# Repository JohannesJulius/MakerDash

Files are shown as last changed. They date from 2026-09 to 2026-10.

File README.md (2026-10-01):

# MakerDash

> Früher „Pico Dashboard“.

Ein selbstgebautes Mischpult für den PC: drei Fader, ein Drehgeber und ein OLED-Display an einem
Raspberry Pi Pico 2 steuern Systemlautstärke, Mikrofon und einzelne Programme unter Windows.

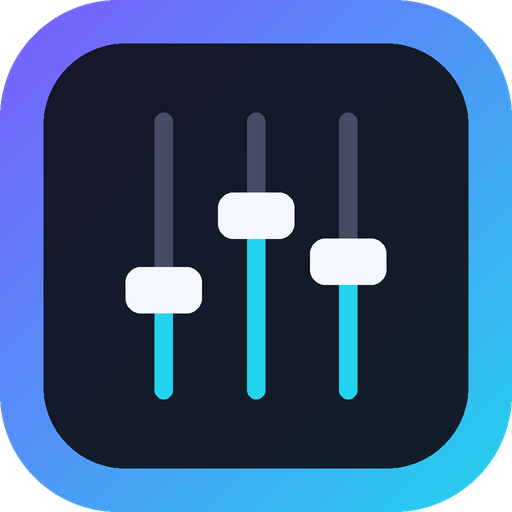
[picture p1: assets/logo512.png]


## Funktionen

- **Fader 1/2:** standardmäßig Systemlautstärke und Mikrofon (in der App frei belegbar)
- **Fader 3:** ein Programm oder eine Gruppe nach Wahl – am Dashboard im Menü oder in der App auswählbar
- **Gruppen** wie in Wave Link: mehrere Programme (z. B. alle Spiele) auf einem Fader
- **Alle Fader frei belegbar:** System, Mikrofon, Programm, Gruppe oder das aktive Fenster
- **Stummschalten** per langem Druck auf den Drehgeber, mit Anzeige auf dem Display
- **Menü am Dashboard:** Programm für Fader 3, Ausgabegerät und Mikrofon umschalten
- **Display:** Start-Animation, Lautstärke-Anzeige, Bildschirmschoner
- **App:** moderne Oberfläche, Live-Anzeige, Umbenennen/Ausblenden von Programmen und Geräten
- **Firmware-Verwaltung:** Die App spielt die Pico-Software selbst auf und aktualisiert sie
- **Automatische Updates** über GitHub Releases

## Installation

1. Neueste `MakerDash-Setup.exe` unter **Releases** herunterladen und starten.
2. Der Einrichtungsassistent führt durch das Anschließen. Ein neuer Pico wird im BOOTSEL-Modus
   (Taste gedrückt halten und einstecken) erkannt und komplett eingerichtet.

Benötigt Windows 10/11 (64 Bit) mit WebView2 Runtime (bei Windows 11 vorinstalliert).

## Verdrahtung (Standard)

| Bauteil | Pin |
|---|---|
| Fader 1 | GP28 |
| Fader 2 | GP27 |
| Fader 3 | GP26 |
| Encoder A / B / Taster | GP10 / GP11 / GP12 |
| OLED SDA / SCL | GP4 / GP5 |
| Fader & OLED Versorgung | 3V3(OUT), GND |

Die Belegung lässt sich in der App unter **Dashboard → Verdrahtung** ändern.

## Neue Version veröffentlichen

1. Versionsnummer in der Datei `VERSION` erhöhen (z. B. `2.1.0`)
2. optional: Beschreibung in `release-notes/v2.1.0.md` anlegen
3. committen und auf `main` pushen

GitHub baut daraufhin App und Installer (`.github/workflows/release.yml`), legt den Tag `v2.1.0` an
und veröffentlicht alles als Release. (Ein gepushter Tag `v*` funktioniert ebenfalls.)
Installierte Apps finden das Update automatisch. Wird `firmware/code.py` (`FW_VERSION`) geändert,
aktualisiert die App danach auch das Dashboard.

> Das Repository muss **öffentlich** sein, damit die App Updates ohne Anmeldung abrufen kann.

## Aufbau

| Pfad | Inhalt |
|---|---|
| `*.go` | Windows-App (Go, ohne cgo) |
| `ui/index.html` | Oberfläche (läuft in WebView2) |
| `firmware/` | Pico-Firmware (CircuitPython), wird in die App eingebettet |
| `installer/` | NSIS-Installer |

Lokal bauen (Linux oder Windows, Go ≥ 1.24):

```bash
GOOS=windows GOARCH=amd64 go build -ldflags "-H windowsgui -X main.AppVersion=2.1.0" -o dist/MakerDash.exe .
cd installer && makensis -DVERSION=2.1.0 setup.nsi
```

Die Bibliotheken in `firmware/lib` stammen von Adafruit (MIT-Lizenz).

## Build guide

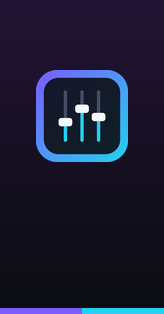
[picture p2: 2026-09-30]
installer/sidebar.bmp

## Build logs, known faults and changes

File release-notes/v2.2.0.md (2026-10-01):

## MakerDash 2.2.0

- **Gruppen** (wie die Kanäle in Wave Link): mehrere Programme zu einer Gruppe zusammenfassen –
  z. B. alle Spiele oder Musik und Browser – und mit einem Fader gemeinsam regeln. Gruppen anlegen
  unter **Programme**; am Dashboard stehen sie im Menü „Fader 3“ ganz oben
- **Alle Fader frei belegbar:** Fader 1 und 2 können jetzt auch ein Programm, eine Gruppe oder das
  aktive Fenster steuern
- **Aktives Fenster:** ein Fader regelt immer das Programm, das gerade im Vordergrund ist
- **Stummschalten per langem Druck** auf den Drehgeber (Standard: Mikrofon, einstellbar unter
  **Dashboard → Anzeige**). Das Display blendet „stumm“/„an“ ein und zeigt oben rechts dauerhaft an,
  wenn stummgeschaltet ist – auch wenn in Windows stummgeschaltet wurde
- Startet ein Programm, das ein Fader regelt, bekommt es sofort die Lautstärke des Faders
- Firmware 2.2.0 (wird von der App automatisch aufgespielt). Ein kurzer Druck auf den Drehgeber
  wirkt jetzt beim Loslassen

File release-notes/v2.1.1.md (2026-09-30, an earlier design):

## MakerDash 2.1.1

- **Behoben:** Schrift im Menü und auf dem Startbild des Dashboards war nach unten verrutscht
- Firmware 2.1.1 (wird von der App automatisch aufgespielt)

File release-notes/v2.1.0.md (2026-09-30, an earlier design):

## MakerDash 2.1.0

**Pico Dashboard heißt jetzt MakerDash.** Einstellungen und Autostart werden automatisch übernommen,
die alte Installation wird beim Update entfernt.

- **Neuer Bildschirmschoner:** Statt das Display abzuschalten, wandert ein gedimmtes MakerDash-Logo
  mit wippenden Mini-Fadern über den Bildschirm
- **Schnelleres Menü am Dashboard:** Schriften werden beim Start vorgeladen, Texte als ein Bild
  gezeichnet und das Display mit 400 kHz angesprochen
- **Neue Geräte-Grafik** in der App nach der Frontplatten-Zeichnung (Display oben, drei Fader,
  Drehgeber unten)
- Firmware 2.1.0 (wird von der App automatisch aufgespielt)

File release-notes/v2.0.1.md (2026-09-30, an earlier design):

## Pico Dashboard 2.0.1

- **Behoben:** Das Fenster blieb schwarz/leer – die Oberfläche wird jetzt zuverlässig angezeigt
- Updates lassen sich jetzt auch direkt über das Tray-Menü installieren (Rechtsklick auf das Symbol)
- Ausführlichere Einträge im Log zur Fehlersuche

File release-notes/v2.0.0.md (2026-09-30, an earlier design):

## Pico Dashboard 2.0

- **Neue Oberfläche** im dunklen Design mit Live-Anzeige der Fader
- **Firmware wird automatisch verwaltet:** Die App erkennt das Dashboard, spielt Updates selbst auf – kein Dateien-Kopieren mehr
- **Neuen Pico einrichten:** CircuitPython wird automatisch heruntergeladen und installiert (BOOTSEL-Modus)
- **Automatische Updates** der App über GitHub
- **Dashboard:** Start-Animation, Lautstärke-Anzeige beim Bewegen eines Faders, Bildschirmschoner
- Pin-Belegung und Anzeige-Einstellungen direkt in der App
- Fader 1 und Fader 3 standardmäßig getauscht (Fader 1 = GP28, Fader 3 = GP26)

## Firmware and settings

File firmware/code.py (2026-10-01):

# MakerDash – Firmware für Raspberry Pi Pico 2 (CircuitPython 9/10)
#
# Diese Datei wird von der App "MakerDash" installiert und aktualisiert.
# Einstellungen (Pins usw.) stehen in settings.toml und werden in der App geändert.

FW_VERSION = "2.2.0"
PROTO = 2
BOOT_MARKER = "DASHBOOT 2"

import os
import math
import time
import board
import busio
import displayio
import i2cdisplaybus
import terminalio
import rotaryio
import keypad
import usb_cdc
import supervisor
import microcontroller
import vectorio
from analogio import AnalogIn
import adafruit_displayio_ssd1306
from adafruit_display_text import bitmap_label
from adafruit_bitmap_font import bitmap_font


# ======================= Einstellungen (settings.toml) =======================

def cfg_str(name, standard):
    try:
        v = os.getenv(name)
    except Exception:
        v = None
    return standard if v is None else str(v)


def cfg_int(name, standard):
    try:
        return int(cfg_str(name, str(standard)))
    except ValueError:
        return standard


def cfg_pin(name, standard):
    return getattr(board, cfg_str(name, standard), getattr(board, standard))


PIN_FADER = (cfg_pin("DASH_FADER1", "GP28"),
             cfg_pin("DASH_FADER2", "GP27"),
             cfg_pin("DASH_FADER3", "GP26"))
FADER_INVERT = cfg_str("DASH_FADER_INVERT", "000")
PIN_ENC_A = cfg_pin("DASH_ENC_A", "GP10")
PIN_ENC_B = cfg_pin("DASH_ENC_B", "GP11")
PIN_ENC_SW = cfg_pin("DASH_ENC_SW", "GP12")
ENC_DIVISOR = cfg_int("DASH_ENC_DIVISOR", 4)
ENC_REVERSE = cfg_int("DASH_ENC_REVERSE", 0)
PIN_SDA = cfg_pin("DASH_SDA", "GP4")
PIN_SCL = cfg_pin("DASH_SCL", "GP5")
I2C_FREQ = cfg_int("DASH_I2C_FREQ", 400000)      # SSD1306 schafft 400 kHz (Fast Mode)
ANIMATION = cfg_int("DASH_ANIMATION", 1)

# Laufzeit-Einstellungen (werden von der App per CFG aktualisiert)
helligkeit = cfg_int("DASH_BRIGHTNESS", 100) / 100
schoner_sek = cfg_int("DASH_SAVER", 300)          # 0 = aus
overlay_an = cfg_int("DASH_OVERLAY", 1)

UNTEN_SCHWELLE = 15         # Fader 3 gilt als "unten" bei Wert <= 15 (von 1000)
BLINK_SEKUNDEN = 0.4
MENU_TIMEOUT = 15
PC_TIMEOUT = 8
OVERLAY_SEK = 1.5
LANG_SEK = 0.7             # so lange gedrückt halten = Stummschalten
AKTIV_SCHWELLE = 15         # so viel muss sich ein Fader bewegen, um als Bedienung zu zählen

# ======================= Hardware =======================

ser = usb_cdc.data
if ser is not None:
    ser.timeout = 0
    ser.write_timeout = 0.05


def senden(zeile):
    if ser is None or not ser.connected:
        return
    try:
        ser.write((zeile + "\n").encode("utf-8"))
    except Exception:
        pass


def boot_ok():
    try:
        with open("/boot_out.txt") as f:
            return BOOT_MARKER in f.read()
    except OSError:
        return False


BOOT_OK = boot_ok()


def boot_pruefen():
    """Nach einem Update ist die neue boot.py erst nach einem Reset aktiv.
    Einmal selbst neu starten; ein Merker im NVM verhindert eine Endlosschleife."""
    try:
        nvm = microcontroller.nvm
    except AttributeError:
        return
    if BOOT_OK:
        if nvm[0] != 0:
            nvm[0] = 0
        return
    try:
        with open("/boot.py") as f:
            neue_boot = BOOT_MARKER in f.read()
    except OSError:
        neue_boot = False
    if neue_boot and nvm[0] != 0xB2:
        nvm[0] = 0xB2
        time.sleep(0.5)
        microcontroller.reset()


boot_pruefen()


class Fader:
    """Liest einen Fader geglättet aus und liefert Werte 0–1000."""

    def __init__(self, pin, invert):
        self.adc = AnalogIn(pin)
        self.invert = invert
        self.gefiltert = self._roh()
        self.wert = self._skaliert(self.gefiltert)
        self.aktiv_wert = self.wert

    def _roh(self):
        s = 0
        for _ in range(8):
            s += self.adc.value
        return s / 8

    def _skaliert(self, roh):
        x = (roh - 400) / (65535 - 800)
        x = max(0.0, min(1.0, x))
        if self.invert:
            x = 1.0 - x
        return int(x * 1000 + 0.5)

    def lesen(self):
        """Neuer Wert bei Änderung, sonst None."""
        self.gefiltert += (self._roh() - self.gefiltert) * 0.3
        neu = self._skaliert(self.gefiltert)
        if abs(neu - self.wert) >= 4 or (neu != self.wert and neu in (0, 1000)):
            self.wert = neu
            return neu
        return None

    def bewegt(self):
        """True, wenn der Fader deutlich bewegt wurde (für Anzeige/Schoner)."""
        if abs(self.wert - self.aktiv_wert) >= AKTIV_SCHWELLE or (
                self.wert != self.aktiv_wert and self.wert in (0, 1000)):
            self.aktiv_wert = self.wert
            return True
        return False


fader = [Fader(PIN_FADER[i], FADER_INVERT[i:i + 1] == "1") for i in range(3)]

if ENC_REVERSE:
    PIN_ENC_A, PIN_ENC_B = PIN_ENC_B, PIN_ENC_A
encoder = rotaryio.IncrementalEncoder(PIN_ENC_A, PIN_ENC_B, divisor=ENC_DIVISOR)
letzte_pos = encoder.position
taster = keypad.Keys((PIN_ENC_SW,), value_when_pressed=False, pull=True)

# ======================= Display =======================
displayio.release_displays()
i2c = busio.I2C(PIN_SCL, PIN_SDA, frequency=I2C_FREQ)
bus = i2cdisplaybus.I2CDisplayBus(i2c, device_address=0x3C)
display = adafruit_displayio_ssd1306.SSD1306(bus, width=128, height=64)

WEISS = 0xFFFFFF
SCHWARZ = 0x000000
FONT_MENU = bitmap_font.load_font("/fonts/menu.bdf")
FONT_GROSS = bitmap_font.load_font("/fonts/big.bdf")
# BDF-Schriften laden Zeichen sonst erst bei Bedarf – jedes neue Zeichen durchsucht dann die
# ganze Datei. Das machte das Menü träge; deshalb nach der Start-Animation alles vorladen.
ZEICHEN = "".join(chr(c) for c in range(32, 127)) + "äöüÄÖÜß°"

PAL_WEISS = displayio.Palette(1)
PAL_WEISS[0] = WEISS


def helligkeit_setzen(wert):
    try:
        display.brightness = max(0.02, min(1.0, wert))
    except Exception:
        pass


helligkeit_setzen(helligkeit)


def rechteck(w, h, x, y):
    return vectorio.Rectangle(pixel_shader=PAL_WEISS, width=w, height=h, x=x, y=y)


def icon(muster, x, y):
    bmp = displayio.Bitmap(len(muster[0]), len(muster), 2)
    for yy, zeile in enumerate(muster):
        for xx, c in enumerate(zeile):
            bmp[xx, yy] = 1 if c == "1" else 0
    pal = displayio.Palette(2)
    pal[0] = SCHWARZ
    pal[1] = WEISS
    pal.make_transparent(0)
    return displayio.TileGrid(bmp, pixel_shader=pal, x=x, y=y)


ICON_LAUTSPRECHER = ("000001000", "000011000", "011111010", "011111001",
                     "011111001", "011111010", "000011000", "000001000")


# bitmap_label zeichnet ein Bitmap pro Text statt einer Kachel pro Buchstabe – deutlich schneller.
# Bei BDF-Schriften hält es aber die Schrifthöhe für die Oberlänge und zentriert auf einen vom Text
# abhängigen Kasten: Texte rutschten 6–9 Pixel nach unten. Mit Anker oben (y = 0) liegt die Schrift
# dagegen immer gleich; diese Tabelle rechnet darauf um, sodass alles wie mit label.Label sitzt.
# Werte je Schrift: (Höhe der Großbuchstaben, Abstand Ankerpunkt -> Oberkante Großbuchstaben)
KORREKTUR = {id(FONT_MENU): (9, 8), id(FONT_GROSS): (13, 9)}
_anker_y = {}


def _y_korrigiert(font, ay, y):
    k = KORREKTUR.get(id(font))
    if k is None:
        return y
    return y - int(ay * k[0]) - k[1]


def text(font, t, anker, pos, farbe=WEISS):
    ax, ay = anker
    bdf = id(font) in KORREKTUR
    lbl = bitmap_label.Label(font, text=t, color=farbe, anchor_point=(ax, 0) if bdf else anker,
                             anchored_position=(pos[0], _y_korrigiert(font, ay, pos[1])))
    _anker_y[id(lbl)] = (ay, pos[1])
    return lbl


def platzieren(lbl, x, y):
    """Wie anchored_position = (x, y), aber mit der Korrektur für BDF-Schriften."""
    ay = _anker_y[id(lbl)][0]
    _anker_y[id(lbl)] = (ay, y)
    lbl.anchored_position = (x, _y_korrigiert(lbl.font, ay, y))


def schrift_setzen(lbl, font, t):
    """Schrift und Text ändern; die Höhe wird für die neue Schrift neu berechnet."""
    if lbl.font is not font:
        lbl.font = font
        ay, y = _anker_y[id(lbl)]
        lbl.anchored_position = (lbl.anchored_position[0], _y_korrigiert(font, ay, y))
    if lbl.text != t:
        lbl.text = t


# --- Startbild ---
start = displayio.Group()
lbl_titel = text(terminalio.FONT, "Fader 3", (0, 0), (0, 0))
lbl_pc = text(terminalio.FONT, "", (1, 0), (127, 0))
# Stumm-Anzeige oben rechts: schwarze Schrift auf weißem Feld
mute_bg = rechteck(1, 11, 0, 0)
mute_bg.hidden = True
lbl_mute = text(terminalio.FONT, "", (1, 0), (125, 0), farbe=SCHWARZ)
lbl_name = text(FONT_GROSS, "", (0, 0.5), (0, 27))
ico_ausgabe = icon(ICON_LAUTSPRECHER, 0, 51)
lbl_ausgabe = text(FONT_MENU, "", (0, 0.5), (12, 55))
lbl_hinweis = text(terminalio.FONT, "", (0.5, 0.5), (64, 55))
for teil in (lbl_titel, lbl_pc, mute_bg, lbl_mute, lbl_name, rechteck(128, 1, 0, 44),
             ico_ausgabe, lbl_ausgabe, lbl_hinweis):
    start.append(teil)

# --- Menü (4 Zeilen, markierte Zeile invertiert) ---
ZEILEN = 4
ZEILENHOEHE = 16
menue = displayio.Group()
balken = rechteck(128, ZEILENHOEHE, 0, 0)
menue.append(balken)
menue_labels = []
menue_pfeile = []
for i in range(ZEILEN):
    mitte = i * ZEILENHOEHE + ZEILENHOEHE // 2
    l = text(FONT_MENU, "", (0, 0.5), (3, mitte))
    p = text(FONT_MENU, "", (1, 0.5), (126, mitte))
    menue.append(l)
    menue.append(p)
    menue_labels.append(l)
    menue_pfeile.append(p)

# --- Lautstärke-Anzeige ---
overlay = displayio.Group()
ov_name = text(FONT_MENU, "", (0.5, 0.5), (64, 8))
ov_wert = text(FONT_GROSS, "", (0.5, 0.5), (64, 30))
ov_rahmen = displayio.Group()
for r in (rechteck(120, 1, 4, 48), rechteck(120, 1, 4, 57), rechteck(1, 10, 4, 48),
          rechteck(1, 10, 123, 48)):
    ov_rahmen.append(r)
ov_fuell = rechteck(1, 6, 6, 50)
for teil in (ov_name, ov_wert, ov_rahmen, ov_fuell):
    overlay.append(teil)

# --- Update-Bildschirm ---
update_bild = displayio.Group()
upd_titel = text(FONT_MENU, "Update", (0.5, 0.5), (64, 12))
upd_text = text(terminalio.FONT, "Wird installiert ...", (0.5, 0.5), (64, 30))
upd_fuell = rechteck(1, 6, 6, 50)
for teil in (upd_titel, upd_text, rechteck(120, 1, 4, 48), rechteck(120, 1, 4, 57),
             rechteck(1, 10, 4, 48), rechteck(1, 10, 123, 48), upd_fuell):
    update_bild.append(teil)


# --- Bildschirmschoner: MakerDash-Logo wandert langsam über das Display ---
schoner = displayio.Group()
sch_knoepfe = []
for i in range(3):
    schoner.append(rechteck(1, 15, 2 + i * 6, 1))
    k = rechteck(5, 3, i * 6, 7)
    schoner.append(k)
    sch_knoepfe.append(k)
schoner.append(text(FONT_MENU, "MakerDash", (0, 0.5), (19, 8)))
SCH_W, SCH_H = 19 + 73, 17
sch_x, sch_y = 10.0, 20.0
sch_dx, sch_dy = 9.0, 5.0             # Pixel pro Sekunde
sch_zeit = 0.0


def schoner_schritt(t):
    """Bewegt das Logo (ca. 20 Bilder/s) und lässt die Mini-Fader wippen."""
    global sch_x, sch_y, sch_dx, sch_dy, sch_zeit
    dt = t - sch_zeit
    if dt < 0.05:
        return
    sch_zeit = t
    dt = min(dt, 0.2)
    sch_x += sch_dx * dt
    sch_y += sch_dy * dt
    if sch_x < 0 or sch_x > 128 - SCH_W:
        sch_dx = -sch_dx
        sch_x = max(0.0, min(128.0 - SCH_W, sch_x))
    if sch_y < 0 or sch_y > 64 - SCH_H:
        sch_dy = -sch_dy
        sch_y = max(0.0, min(64.0 - SCH_H, sch_y))
    schoner.x = int(sch_x)
    schoner.y = int(sch_y)
    for i, k in enumerate(sch_knoepfe):
        k.y = int(7 + 6 * math.sin(t * 1.6 + i * 2.1))


def start_animation():
    """Kurzes Logo beim Einschalten: drei Fader schieben sich in Position."""
    g = displayio.Group()
    spuren_x = (12, 24, 36)
    knoepfe = []
    for x in spuren_x:
        g.append(rechteck(1, 48, x, 8))
        k = rechteck(9, 5, x - 4, 51)
        g.append(k)
        knoepfe.append(k)
    t_gross = text(FONT_GROSS, "Maker", (0, 0.5), (128, 20))
    t_klein = text(FONT_GROSS, "Dash", (0, 0.5), (128, 42))
    t_ver = text(terminalio.FONT, "v" + FW_VERSION, (1, 1), (127, 64))
    t_ver.hidden = True
    for t in (t_gross, t_klein, t_ver):
        g.append(t)
    display.root_group = g
    ziele = (0.25, 0.7, 0.45)
    t0 = time.monotonic()
    dauer = 1.6
    while True:
        t = time.monotonic() - t0
        if t > dauer:
            break
        for i, k in enumerate(knoepfe):
            p = max(0.0, min(1.0, (t - i * 0.12) / 0.7))
            p = 1 - (1 - p) ** 3                      # sanft abbremsen
            k.y = int(51 - p * ziele[i] * 43)
        p = max(0.0, min(1.0, (t - 0.35) / 0.6))
        p = 1 - (1 - p) ** 3
        x = int(128 - p * (128 - 50))
        platzieren(t_gross, x, 20)
        p2 = max(0.0, min(1.0, (t - 0.5) / 0.6))
        p2 = 1 - (1 - p2) ** 3
        platzieren(t_klein, int(128 - p2 * (128 - 50)), 42)
        t_ver.hidden = t < 1.0
        time.sleep(0.015)
    return time.monotonic()


def schriften_vorladen():
    for f in (FONT_MENU, FONT_GROSS):
        try:
            f.load_glyphs(ZEICHEN)
        except Exception:
            pass


if ANIMATION:
    ende = start_animation()
    schriften_vorladen()                       # läuft, während das Logo noch steht
    rest = 0.5 - (time.monotonic() - ende)
    if rest > 0:
        time.sleep(rest)
else:
    schriften_vorladen()

# ======================= Zustand =======================
apps = []
ausgaben = []
ausgabe_idx = -1
mikros = []
mikro_idx = -1
f3_name = "-"
namen = ["Fader 1", "Fader 2", "Fader 3"]
gesperrt = False
letzte_rx = -100.0
modus = "START"         # START, HAUPT, PROG, AUSGABE, MIKRO
cursor = 0
scroll = 0
jetzt = time.monotonic()
letzte_eingabe = jetzt
letzte_aktivitaet = jetzt
overlay_bis = 0.0
schlaeft = False
gedimmt = False
update_laeuft = False
rx_puffer = b""
mute_an = False
mute_name = ""
mute_bekannt = False        # erst nach der ersten Meldung vom PC Änderungen einblenden
taste_seit = None           # Zeitpunkt, seit dem der Taster gedrückt ist
taste_lang = False


def pc_da():
    return ser is not None and ser.connected and time.monotonic() - letzte_rx < PC_TIMEOUT


def eintraege(m=None):
    """Liste aus (Text, Pfeil, Wert)."""
    modus_ = m or modus
    if modus_ == "HAUPT":
        return [("Zurück", False, None), ("Fader 3", True, None),
                ("Ausgabe", True, None), ("Mikrofon", True, None)]
    liste = [("Zurück", False, None)]
    if not pc_da():
        return liste + [("(kein PC)", False, None)]
    if modus_ == "PROG":
        if not apps:
            liste.append(("(kein Ton aktiv)", False, None))
        for n in apps:
            liste.append((("* " if n == f3_name else "  ") + n, False, n))
    elif modus_ == "AUSGABE":
        for i, n in enumerate(ausgaben):
            liste.append((("* " if i == ausgabe_idx else "  ") + n, False, n))
    elif modus_ == "MIKRO":
        if not mikros:
            liste.append(("(kein Mikrofon)", False, None))
        for i, n in enumerate(mikros):
            liste.append((("* " if i == mikro_idx else "  ") + n, False, n))
    return liste


def menue_zeichnen():
    global scroll, cursor
    liste = eintraege()
    cursor = max(0, min(cursor, len(liste) - 1))
    if cursor < scroll:
        scroll = cursor
    elif cursor >= scroll + ZEILEN:
        scroll = cursor - ZEILEN + 1
    scroll = max(0, min(scroll, max(0, len(liste) - ZEILEN)))
    for zeile in range(ZEILEN):
        idx = scroll + zeile
        t, pfeil, _ = liste[idx] if idx < len(liste) else ("", False, None)
        farbe = SCHWARZ if idx == cursor else WEISS
        # nur Geändertes anfassen – jede Änderung kostet Rechenzeit und Übertragung
        lbl, pf = menue_labels[zeile], menue_pfeile[zeile]
        if lbl.text != t:
            lbl.text = t
        if lbl.color != farbe:
            lbl.color = farbe
        p = ">" if pfeil else ""
        if pf.text != p:
            pf.text = p
        if pf.color != farbe:
            pf.color = farbe
    y = (cursor - scroll) * ZEILENHOEHE
    if balken.y != y:
        balken.y = y


def gross_setzen(lbl, t):
    schrift_setzen(lbl, FONT_GROSS, t)
    if lbl.bounding_box[2] > 124:
        schrift_setzen(lbl, FONT_MENU, t)


def start_zeichnen():
    if lbl_name.text != f3_name:
        gross_setzen(lbl_name, f3_name)
    da = pc_da()
    lbl_pc.text = "" if da else "kein PC"
    m = ""
    if da and mute_an:
        m = mute_name + " aus"
        if len(m) > 13:
            m = "STUMM"
    if lbl_mute.text != m:
        lbl_mute.text = m
        if m:
            w = lbl_mute.bounding_box[2]
            mute_bg.x = 125 - w - 2
            mute_bg.width = w + 4
    mute_bg.hidden = not m
    aus = ausgaben[ausgabe_idx] if 0 <= ausgabe_idx < len(ausgaben) else "-"
    if lbl_ausgabe.text != aus:
        lbl_ausgabe.text = aus


def bild_zeigen():
    """Zeigt das zum Zustand passende Bild."""
    if schlaeft and not update_laeuft:
        display.root_group = schoner
    elif update_laeuft:
        display.root_group = update_bild
    elif time.monotonic() < overlay_bis:
        display.root_group = overlay
    elif modus == "START":
        start_zeichnen()
        display.root_group = start
    else:
        menue_zeichnen()
        display.root_group = menue


def gehe_zu(neuer_modus, neuer_cursor=0):
    global modus, cursor, scroll, overlay_bis
    modus = neuer_modus
    cursor = neuer_cursor
    scroll = 0
    overlay_bis = 0
    bild_zeigen()


def cursor_auf(ziel_modus, name, standard=1):
    for i, (_, _, wert) in enumerate(eintraege(ziel_modus)):
        if wert is not None and wert == name:
            return i
    return standard


def overlay_zeigen(i):
    global overlay_bis
    if not overlay_an or update_laeuft:
        return
    ov_name.text = namen[i]
    if i == 2 and gesperrt:
        schrift_setzen(ov_wert, FONT_MENU, "ganz runter!")
    else:
        schrift_setzen(ov_wert, FONT_GROSS, "%d %%" % ((fader[i].wert + 5) // 10))
    ov_fuell.width = max(1, fader[i].wert * 116 // 1000)
    ov_rahmen.hidden = False
    ov_fuell.hidden = False
    overlay_bis = time.monotonic() + OVERLAY_SEK
    if display.root_group is not overlay:
        display.root_group = overlay


def overlay_text(name, wert):
    """Einblendung ohne Balken, z. B. "Mikrofon / stumm"."""
    global overlay_bis
    if not overlay_an or update_laeuft:
        return
    ov_name.text = name
    schrift_setzen(ov_wert, FONT_GROSS, wert)
    ov_rahmen.hidden = True
    ov_fuell.hidden = True
    overlay_bis = time.monotonic() + OVERLAY_SEK
    if display.root_group is not overlay:
        display.root_group = overlay


def aufwachen():
    """Bildschirmschoner beenden. Gibt True zurück, wenn der Bildschirm aus war."""
    global schlaeft, gedimmt, letzte_aktivitaet
    letzte_aktivitaet = time.monotonic()
    war_aus = schlaeft
    if schlaeft:
        schlaeft = False
        bild_zeigen()
    if gedimmt:
        helligkeit_setzen(helligkeit)
        gedimmt = False
    return war_aus


def taster_gedrueckt():
    global f3_name, gesperrt, ausgabe_idx, mikro_idx
    if modus == "START":
        gehe_zu("HAUPT", 1)
        return
    if modus == "HAUPT":
        if cursor == 0:
            gehe_zu("START")
        elif cursor == 1:
            gehe_zu("PROG", cursor_auf("PROG", f3_name))
        elif cursor == 2:
            aktiv = ausgaben[ausgabe_idx] if 0 <= ausgabe_idx < len(ausgaben) else None
            gehe_zu("AUSGABE", cursor_auf("AUSGABE", aktiv))
        else:
            aktiv = mikros[mikro_idx] if 0 <= mikro_idx < len(mikros) else None
            gehe_zu("MIKRO", cursor_auf("MIKRO", aktiv))
        return
    _, _, wert = eintraege()[cursor]
    if cursor == 0:
        gehe_zu("HAUPT", {"PROG": 1, "AUSGABE": 2, "MIKRO": 3}[modus])
    elif wert is None:
        pass
    elif modus == "PROG":
        if wert != f3_name:
            f3_name = wert
            namen[2] = wert
            gesperrt = True
        senden("SETAPP\t" + wert)
        gehe_zu("START")
    elif modus == "AUSGABE":
        if wert in ausgaben:
            ausgabe_idx = ausgaben.index(wert)
        senden("SETOUT\t" + wert)
        gehe_zu("START")
    elif modus == "MIKRO":
        if wert in mikros:
            mikro_idx = mikros.index(wert)
        senden("SETIN\t" + wert)
        gehe_zu("START")


def fader_senden(i, wert):
    senden("F\t%d\t%d" % (i + 1, wert))


def cfg_anwenden(teile):
    global helligkeit, schoner_sek, overlay_an
    for k in range(0, len(teile) - 1, 2):
        schluessel, wert = teile[k], teile[k + 1]
        try:
            if schluessel == "brightness":
                helligkeit = int(wert) / 100
                if not gedimmt:
                    helligkeit_setzen(helligkeit)
            elif schluessel == "saver":
                schoner_sek = int(wert)
            elif schluessel == "overlay":
                overlay_an = int(wert)
        except ValueError:
            pass
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

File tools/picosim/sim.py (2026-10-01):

import os, sys, types, time as _rt
from PIL import Image, ImageFont, ImageDraw

# Mit "pip install adafruit-blinka-displayio" laufen displayio, Schriften und Labels mit den echten
# Adafruit-Bibliotheken aus firmware/lib – die Bilder entsprechen dann pixelgenau dem Display.
# Ohne Blinka (oder mit SIM_FAKE=1) gibt es eine vereinfachte Nachbildung (Textpositionen ungenau).
_FWDIR = os.path.join(os.path.dirname(os.path.abspath(__file__)), "..", "..", "firmware")
REAL = os.environ.get("SIM_FAKE") is None
if REAL:
    try:
        sys.path.insert(0, os.path.join(_FWDIR, "lib"))
        import displayio as _rdio, vectorio as _rvio, terminalio as _rterm
        from adafruit_bitmap_font import bitmap_font as _rbf
        import adafruit_display_text as _radt
        from adafruit_display_text import bitmap_label as _rbl, label as _rlab
    except ImportError:
        REAL = False

# ---------- virtuelle Zeit & Szenario ----------
CLOCK = [0.0]
SCENARIO = None
class Stop(Exception): pass

tm = types.ModuleType("time")
tm.monotonic = lambda: CLOCK[0]
def _sleep(s):
    CLOCK[0] += max(s, 0.005)
    SCENARIO.tick()
tm.sleep = _sleep
sys.modules["time"] = tm

# ---------- board / busio ----------
board = types.ModuleType("board")
for n in ["GP%d" % i for i in range(29)]: setattr(board, n, n)
sys.modules["board"] = board
busio = types.ModuleType("busio"); busio.I2C = lambda scl, sda, frequency=100000: ("i2c", scl, sda, frequency); sys.modules["busio"] = busio

# ---------- analog ----------
ADC = {}
analogio = types.ModuleType("analogio")
class AnalogIn:
    def __init__(self, pin): self.pin = pin; ADC.setdefault(pin, 30000)
    @property
    def value(self): return ADC[self.pin]
analogio.AnalogIn = AnalogIn; sys.modules["analogio"] = analogio

# ---------- rotaryio / keypad ----------
ENC = {"pos": 0}
rotaryio = types.ModuleType("rotaryio")
class IncrementalEncoder:
    def __init__(self, a, b, divisor=4): pass
    @property
    def position(self): return ENC["pos"]
rotaryio.IncrementalEncoder = IncrementalEncoder; sys.modules["rotaryio"] = rotaryio
KEYQ = []
keypad = types.ModuleType("keypad")
class _Ev:
    def __init__(self, p): self.pressed = p; self.released = not p
class _Events:
    def get(self): return KEYQ.pop(0) if KEYQ else None
class Keys:
    def __init__(self, pins, value_when_pressed, pull): self.events = _Events()
keypad.Keys = Keys; sys.modules["keypad"] = keypad

# ---------- usb_cdc ----------
class Ser:
    def __init__(self): self.rx = b""; self.tx = []; self.connected = True; self.timeout = None; self.write_timeout = None
    @property
    def in_waiting(self): return len(self.rx)
    def read(self, n): d, self.rx = self.rx[:n], self.rx[n:]; return d
    def write(self, b): self.tx.append(b.decode()); return len(b)
usb_cdc = types.ModuleType("usb_cdc"); usb_cdc.data = Ser(); sys.modules["usb_cdc"] = usb_cdc

# ---------- Fonts ----------
class BDF:
    def __init__(self, path):
        self.g = {}; cur = None; L = open(path).read().split("\n"); i = 0
        for l in L:
            if l.startswith("FONT_ASCENT"): self.ascent = int(l.split()[1])
            if l.startswith("FONT_DESCENT"): self.descent = int(l.split()[1])
        while i < len(L):
            l = L[i]
            if l.startswith("ENCODING"): cur = {"c": int(l.split()[1])}
            elif l.startswith("DWIDTH"): cur["adv"] = int(l.split()[1])
            elif l.startswith("BBX"): cur["bbx"] = list(map(int, l.split()[1:]))
            elif l == "BITMAP":
                rows = []; i += 1
                while L[i] != "ENDCHAR": rows.append(int(L[i], 16)); i += 1
                cur["rows"] = rows; self.g[cur["c"]] = cur
            i += 1
    def width(self, s): return sum(self.g[ord(c)]["adv"] for c in s if ord(c) in self.g)
    def load_glyphs(self, s): pass
    def draw(self, img, x, base, s, col):
        for ch in s:
            c = self.g.get(ord(ch))
            if not c: continue
            w, h, xo, yo = c["bbx"]; nb = (w + 7) // 8
            for r, v in enumerate(c["rows"]):
                for k in range(w):
                    if v >> (nb * 8 - 1 - k) & 1:
                        px, py = x + xo + k, base - yo - h + 1 + r
                        if 0 <= px < 128 and 0 <= py < 64: img.putpixel((px, py), col)
            x += c["adv"]
class TermFont:  # Näherung der 6x12-Terminalschrift
    ascent, descent = 9, 3
    pil = ImageFont.load_default()
    def width(self, s): return 6 * len(s)
    def draw(self, img, x, base, s, col):
        d = ImageDraw.Draw(img)
        for i, ch in enumerate(s): d.text((x + 6 * i, base - 9), ch, fill=col, font=self.pil)
terminalio = types.ModuleType("terminalio"); terminalio.FONT = TermFont(); sys.modules["terminalio"] = terminalio
abf = types.ModuleType("adafruit_bitmap_font"); bfm = types.ModuleType("adafruit_bitmap_font.bitmap_font")
import os.path as _p
_FW = _p.join(_p.dirname(_p.abspath(__file__)), "..", "..", "firmware")
bfm.load_font = lambda p: BDF(_p.join(_FW, p.lstrip("/"))); abf.bitmap_font = bfm
sys.modules["adafruit_bitmap_font"] = abf; sys.modules["adafruit_bitmap_font.bitmap_font"] = bfm

# ---------- displayio ----------
dio = types.ModuleType("displayio")
class Group(list):
    hidden = False
    x = 0
    y = 0
dio.Group = Group
class Bitmap:
    def __init__(self, w, h, n): self.w, self.h = w, h; self.d = {}
    def __setitem__(self, k, v): self.d[k] = v
    def __getitem__(self, k): return self.d.get(k, 0)
class Palette(list):
    def __init__(self, n): super().__init__([0] * n); self.transp = set()
    def make_transparent(self, i): self.transp.add(i)
class TileGrid:
    def __init__(self, bmp, pixel_shader, x=0, y=0): self.bmp, self.pal, self.x, self.y = bmp, pixel_shader, x, y; self.hidden = False
dio.Bitmap, dio.Palette, dio.TileGrid = Bitmap, Palette, TileGrid
dio.release_displays = lambda: None
sys.modules["displayio"] = dio
i2cdb = types.ModuleType("i2cdisplaybus"); i2cdb.I2CDisplayBus = lambda i2c, device_address: None; sys.modules["i2cdisplaybus"] = i2cdb
DISPLAY = {}
ssd = types.ModuleType("adafruit_displayio_ssd1306")
class SSD1306:
    def __init__(self, bus, width, height): self.root_group = None; self.brightness = 1.0; self.awake = True; DISPLAY["d"] = self
    def sleep(self): self.awake = False
    def wake(self): self.awake = True
ssd.SSD1306 = SSD1306; sys.modules["adafruit_displayio_ssd1306"] = ssd
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

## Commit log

2026-09-30 Pico Dashboard 2.0
    Neue App mit moderner Oberfläche (WebView2), automatischer Firmware-
    Verwaltung für den Pico, Einrichtungsassistent, Updates über GitHub
    Releases und Firmware 2.0 (Start-Animation, Lautstärke-Anzeige,
    Bildschirmschoner). Fader 1 und 3 standardmäßig getauscht.
    Claude-Session: https://claude.ai/code/session_01RkVi4yqMmRNsHRVCSwUZ6J
2026-09-30 2.0.1: leeres Fenster behoben, Update über Tray-Menü
    WebView2 wird jetzt erst in das sichtbare Fenster eingebettet und nach
    dem Anzeigen explizit sichtbar geschaltet. Dazu Diagnose im Log und ein
    Ausweichweg, der die Oberfläche aus einer Datei lädt.
    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
2026-09-30 Projektkontext (CLAUDE.md) und Testwerkzeuge für weitere Sessions
    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
2026-09-30 MakerDash 2.1.0: neuer Name, animierter Bildschirmschoner, schnelleres Menü, neue Geräte-Grafik
    - Umbenennung Pico Dashboard -> MakerDash (App, Installer, Workflows, Update-Quelle
    JohannesJulius/makerdash). legacy.go übernimmt %APPDATA%-Ordner und Autostart,
    der Installer entfernt die alte Installation. Das Release enthält zusätzlich
    PicoDashboard-Setup.exe, damit Apps bis 2.0.x das Update finden.
    - Firmware 2.1.0: Bildschirmschoner zeigt ein gedimmtes, wanderndes Logo statt
    das Display abzuschalten; Menü schneller durch vorgeladene Glyphen, bitmap_label,
    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
2026-09-30 2.1.1: verrutschte Schrift auf dem Dashboard-Display behoben
    bitmap_label (adafruit_display_text 5.0.5) nimmt bei BDF-Schriften die
    Schrifthöhe als Oberlänge und zentriert auf einen textabhängigen Kasten –
    Texte lagen dadurch 6–9 Pixel zu tief. Die Firmware verankert BDF-Texte
    jetzt oben (dort ist die Lage textunabhängig) und rechnet die gewünschte
    Position über eine Tabelle je Schrift um. Schriftwechsel und Verschieben
    laufen über schrift_setzen/platzieren.
    tools/picosim/test_labels.py vergleicht alle Texte der Firmware mit den
    echten Adafruit-Bibliotheken gegen label.Label.
    Claude-Session: https://claude.ai/code/session_0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
    [code.py, test_labels.py]
2026-10-01 2.2.0: Gruppen, frei belegbare Fader, aktives Fenster, Stummschalten per langem Druck
    - Gruppen wie die Kanäle in Wave Link: mehrere Programme auf einem Fader
    (Config.Groups, Ziel "group:<id>"); in der App unter Programme verwaltet,
    am Dashboard im Menü "Fader 3" ganz oben.
    - Fader 1 und 2 können jetzt auch Programme, Gruppen oder das aktive Fenster
    ("focus") steuern.
    - Langer Druck auf den Drehgeber schaltet ein wählbares Ziel stumm (Standard:
    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
